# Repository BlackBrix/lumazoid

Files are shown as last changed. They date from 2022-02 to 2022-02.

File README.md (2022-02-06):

# Lumazoid

Firmware for the Lumazoid realtime music visualizer board from nootropic design.
Detailed technical information about Lumazoid is at http://nootropicdesign.com/lumazoid  
  
Shop: https://nootropicdesign.com/store/product-category/led-controllers/  
  
Install libraries/ffft in your Arduino sketchbook libraries folder.

Requires the [Adafruit NeoPixel library](https://github.com/adafruit/Adafruit_NeoPixel). 
Your directory structure should look like this:

```
your_sketchbook
 |
 +--libraries
 |   |
 |   +--ffft
 |   |
 |   +--Adafruit_NeoPixel
 |
 +--Lumazoid
     |
     +--Lumazoid.h
     +--Lumazoid.ino
```

In the Arduino IDE, select board type "Arduino Uno" to upload to the Lumazoid.  
  
https://youtu.be/Vjp7iLEZsX4  
https://youtu.be/2BDE81b42Ac  
https://youtu.be/lYz1uqOQcGg  
https://youtu.be/453p5HPAYZY  
https://youtu.be/N-TBdfP13BE  
  
Forum:  
https://nootropicdesign.com/store/forums/

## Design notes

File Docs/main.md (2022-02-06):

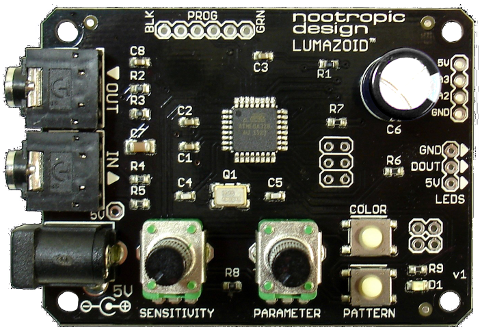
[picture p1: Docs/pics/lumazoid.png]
<div class="et_builder_inner_content et_pb_gutters3"><div class="et_pb_section et_pb_section_0 et_pb_with_background et_section_regular"><div class="et_pb_row et_pb_row_0"><div class="et_pb_column et_pb_column_1_2 et_pb_column_0  et_pb_css_mix_blend_mode_passthrough"><div class="et_pb_module et_pb_image et_pb_image_0 et_pb_image_sticky"><a href="https://nootropicdesign.com/"><span class="et_pb_image_wrap "></span></a></div></div><div class="et_pb_column et_pb_column_1_2 et_pb_column_1  et_pb_css_mix_blend_mode_passthrough et-last-child"><div class="et_pb_button_module_wrapper et_pb_button_0_wrapper et_pb_button_alignment_right et_pb_button_alignment_tablet_left et_pb_button_alignment_phone_left et_pb_module "><a class="et_pb_button et_pb_button_0 et_pb_bg_layout_light" href="/store/product-category/led-controllers/">Buy</a></div></div></div><div class="et_pb_row et_pb_row_1"><div class="et_pb_column et_pb_column_4_4 et_pb_column_2  et_pb_css_mix_blend_mode_passthrough et-last-child"><div class="et_pb_module et_pb_image et_pb_image_1 et_pb_image_sticky"><span class="et_pb_image_wrap "></span></div><div class="et_pb_module et_pb_text et_pb_text_0  et_pb_text_align_left et_pb_bg_layout_light"><div class="et_pb_text_inner"><p>Realtime music visualizer board for LED strips</p></div></div><div class="et_pb_module et_pb_text et_pb_text_1  et_pb_text_align_left et_pb_bg_layout_light"><div class="et_pb_text_inner"><span style="color: #ff5500;">Details</span> | <a href="faq/">FAQ</a> | <a href="/forum/">Forum</a> | <a href="design/">Design Info</a></div></div></div></div><div class="et_pb_row et_pb_row_2"><div class="et_pb_column et_pb_column_1_2 et_pb_column_3  et_pb_css_mix_blend_mode_passthrough"><div class="et_pb_module et_pb_image et_pb_image_2"><span class="et_pb_image_wrap "></span></div></div><div class="et_pb_column et_pb_column_1_2 et_pb_column_4  et_pb_css_mix_blend_mode_passthrough et-last-child"><div class="et_pb_module et_pb_text et_pb_text_2  et_pb_text_align_left et_pb_bg_layout_light"><div class="et_pb_text_inner"><p><span>Lumazoid is a realtime music visualizer board that lets you display an awesome light show that is synchronized to your music. Just plug the Lumazoid in between your music device and your audio system, and enjoy the show!</span></p><ul><li>Works with any WS2812 / WS2812B LED strips like NeoPixel and others</li><li>Supports 60, 120, or 180 LED strip lengths. (video below shows a 2m 120 LED strip)</li><li>8 different patterns + random mode that smoothly transitions between patterns</li><li>3 different color modes with parameter control</li><li>Sensitivity and brightness control</li><li>Adjustable frequency response so you can choose to visualize all frequency bands or just the bass and beat</li><li>Programmable with Arduino</li><li>Fully assembled and tested</li></ul></div></div></div></div><div class="et_pb_row et_pb_row_3"><div class="et_pb_column et_pb_column_4_4 et_pb_column_5  et_pb_css_mix_blend_mode_passthrough et-last-child"><div class="et_pb_module et_pb_video et_pb_video_0"><div class="et_pb_video_box">
  
  youtube-video (https://www.youtube.com/watch?v=2BDE81b42Ac)

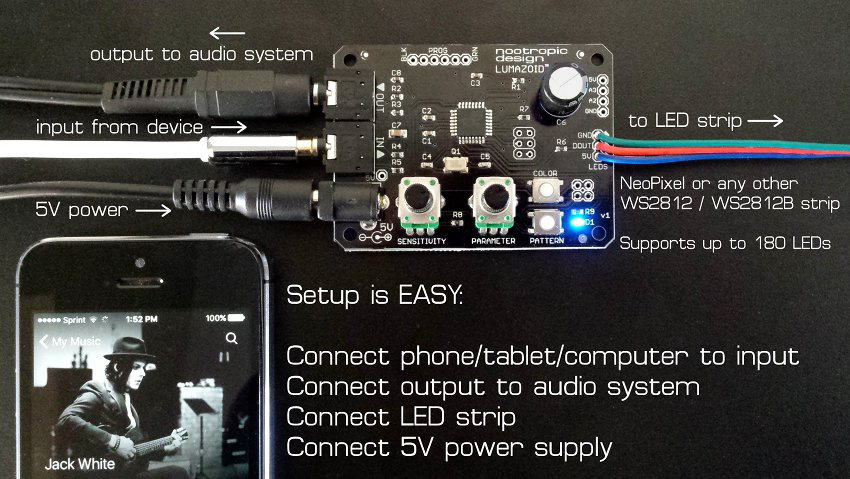
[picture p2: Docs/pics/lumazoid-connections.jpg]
  </div></div></div></div><div class="et_pb_row et_pb_row_4"><div class="et_pb_column et_pb_column_4_4 et_pb_column_6  et_pb_css_mix_blend_mode_passthrough et-last-child"><div class="et_pb_module et_pb_text et_pb_text_3  et_pb_text_align_left et_pb_bg_layout_light"><div class="et_pb_text_inner"><h2>Connection Guide</h2><p><span class="highlight">Input</span>: 3.5mm (1/8″) stereo jack from phone, tablet, computer, Bluetooth receiver or other device.</p><p><span class="highlight">Output</span>: 3.5mm (1/8″) stereo jack to audio system like stereo receiver or amplified computer speakers.</p><p><span class="highlight">LEDs</span>: 3-wire connection to WS2812 / WS2812B LED strip. No wires will be connected if you buy just the board, but if you buy an LED strip from us the Lumazoid board will have a compatible wire harness connected for you.</p><p><span class="highlight">Power</span>: 5V, standard 2.1mm size, center positive</p></div></div></div></div><div class="et_pb_row et_pb_row_5"><div class="et_pb_column et_pb_column_4_4 et_pb_column_7  et_pb_css_mix_blend_mode_passthrough et-last-child"><div class="et_pb_module et_pb_image et_pb_image_3"><span class="et_pb_image_wrap "></span></div></div></div><div class="et_pb_row et_pb_row_6"><div class="et_pb_column et_pb_column_4_4 et_pb_column_8  et_pb_css_mix_blend_mode_passthrough et-last-child"><div class="et_pb_module et_pb_text et_pb_text_4  et_pb_text_align_left et_pb_bg_layout_light"><div class="et_pb_text_inner"><h2>Technical Details</h2><h3>Power</h3><p>The Lumazoid board requires a 5V DC power supply (available in our store). The power supply must be capable of supplying 2A of current when using the Lumazoid with 60 or 120 LEDs (for example, a 1m or 2m strip with 60 LEDs per meter). The Lumazoid firmware is carefully designed to draw less than 2A of current when used with 60 or 120 LEDs. If you use the Lumazoid with a 180 LED strip, you will require a supply that can deliver at least 3A of current, but you probably already have such a power supply if you have that many LEDs. We only sell 2A power supplies at this time.</p><p>If you design and code your own visualizations for Lumazoid, make sure you consider the current requirements of your visualization.</p><h3>LED Strip Compatibility</h3><p>The Lumazoid is designed for WS2812 or WS2812B LED strips. These are readily available from many suppliers (including us) and are sometimes referred to as “NeoPixel” which is Adafruit’s branding for WS2812B strips. Sometimes LED strips are referred to as “WS2811” but the name WS2811 only refers to the driver chip and not the integrated chip+LED combo. If you have an LED strip that someone called “WS2811” and it has 3 wires (5V, ground, and data) then it should work.</p><p><i>The Lumazoid does NOT work</i><span>¨NBSP;</span>with other types of LED strips based on different technology like APA102 and APA104 LEDs (for example, Adafruit “DotStar” strips). Lumazoid only works with 3-wire LED strips based on WS2812 or WS2812B technology.</p><p><span class="highlight">IMPORTANT</span>: When connecting the LED strip to the Lumazoid, carefully pay attention to the labels for the connections (GND, DOUT, 5V). The Lumazoid DOUT connects to the LED strip “DI” or “DIN” connection. Do not assume that the wire colors will match or that the order will match! The top-to-bottom ordering of connections on the Lumazoid board is GND, DOUT, 5V, and this order may be different on your LED strip. If you buy an LED strip from us, the order will match. If you buy a Lumazoid Bundle from us (Lumazoid board, power supply, LED strip) the board will have a wire harness that is compatible with the LED strip and you have nothing to worry about.</p><p><span class="highlight">IMPORTANT</span>: Always connect the LED strip before connecting power. Do not connect the LED strip to a powered board.</p></div></div></div></div><div class="et_pb_row et_pb_row_7"><div class="et_pb_column et_pb_column_4_4 et_pb_column_9  et_pb_css_mix_blend_mode_passthrough et-last-child"><div class="et_pb_module et_pb_text et_pb_text_5  et_pb_text_align_left et_pb_bg_layout_light"><div class="et_pb_text_inner"><h2>Instructions for Use</h2><h3>Initial Setup Configuration</h3><p>Before using your Lumazoid, you may need to configure it for your LED strip length and optionally adjust the brightness. By default, the Lumazoid is configured to use a 120 LED strip (for example, a 2m strip with 60 LEDs per meter) and is set for maximum brightness. If you have a different LED stip length or would like to reduce the brighness, follow these instructions.</p></div></div></div></div><div class="et_pb_row et_pb_row_8"><div class="et_pb_column et_pb_column_4_4 et_pb_column_10  et_pb_css_mix_blend_mode_passthrough et-last-child"><div class="et_pb_module et_pb_video et_pb_video_1"><div class="et_pb_video_box">

youtube-video (https://www.youtube.com/watch?v=453p5HPAYZY)

</div></div></div></div><div class="et_pb_row et_pb_row_9"><div class="et_pb_column et_pb_column_4_4 et_pb_column_11  et_pb_css_mix_blend_mode_passthrough et-last-child"><div class="et_pb_module et_pb_text et_pb_text_6  et_pb_text_align_left et_pb_bg_layout_light"><div class="et_pb_text_inner"><p><span class="highlight">Brightness</span>: hold the color button when connecting power. A rainbow of LEDs will be displayed on the first 8 LEDs. Use the parameter knob to change the brightness. When finished, press the color button again and your configuration will be saved to memory. This will be remembered even if power is disconnected.</p><p><span class="highlight">LED strip length</span>: hold the pattern button when connecting power. One, two, or three red LEDs will be displayed. Used the parameter knob to choose your LED strip configuration based on the number of red LEDs:</p><ol><li>60 LEDs</li><li>120 LEDs</li><li>180 LEDs</li></ol><p>When finished, press the pattern button again and your configuration will be saved to memory. This will be remembered even if power is disconnected.</p><h3>Volume and Sensitivity Adjustment</h3><p>Lumazoid works best when your music device volume is set to a high level. Smaller devices like phones and tablets will need their volume turned up to the highest level. Use the sensitivity knob to adjust the sensitivity of the Lumazoid. Small devices will require a higher sensitivity setting. A music device like a computer may not need a high sensitivity at all. Just experiment with your device to ensure that Lumazoid is responding to the music the way you desire.</p><h3>Patterns, Color Modes, and Frequency Response</h3><p>Lumazoid lets you choose from different LED patterns and color modes. You can also adjust the frequency response.</p></div></div></div></div><div class="et_pb_row et_pb_row_10"><div class="et_pb_column et_pb_column_4_4 et_pb_column_12  et_pb_css_mix_blend_mode_passthrough et-last-child"><div class="et_pb_module et_pb_video et_pb_video_2"><div class="et_pb_video_box">

youtube-video (https://www.youtube.com/watch?v=N-TBdfP13BE)
  
  </div></div></div></div><div class="et_pb_row et_pb_row_11"><div class="et_pb_column et_pb_column_4_4 et_pb_column_13  et_pb_css_mix_blend_mode_passthrough et-last-child"><div class="et_pb_module et_pb_text et_pb_text_7  et_pb_text_align_left et_pb_bg_layout_light"><div class="et_pb_text_inner"><p><b class="highlight">Patterns:<span></span></b>Lumazoid has different display patterns for visualizing the audio signal peaks (high amplitude) detected in music. Lumazoid is like a graphic equalizer that shows the strength of different frequency bands, but Lumazoid displays the information in a much more interesting way. There are 8 different patterns for displaying the audio peaks in the music. Press the pattern button to cycle through them. A white LED indicates which pattern is selected. The 9th pattern is “random” mode which is indicated by a red LED. This mode changes the pattern randomly with a random time interval. The 8 patterns are:</p><ol><li><b>Dance Party</b>: Audio signal peaks are emitted from the center of the strip and fade out as they approach the ends. The speed of the peak is proportional to the audio signal magnitude of that peak.</li><li><b>Dance Party 2</b>: Same as Dance Party but the signal peaks are emitted from one end.</li><li><b>Pulse</b>: Signal peaks are displayed as bright pulses that come from the center of the strip. The width of the pulse is based on signal peak magnitude.</li><li><b>Light Bar</b>: Signal peaks illuminate the entire strip. There is some subtle color variation between LEDs and some motion to make it more interesting.</li><li><b>Color Bars</b>: Signal peaks displayed as colored bars that fade out.</li><li><b>Color Bars 2</b>: Similar to Color Bars but each bar shrinks in size as it fades out.</li><li><b>Flash Bulbs</b>: Signal peaks are displayed as a single-LED flash at a random location. The initial color is white and then fades as a different color.</li><li><b>Fireflies</b>: Signal peaks displayed as single LEDs at a random location and they move left or right as they fade out. Their speed is based on the signal peak magnitude.</li></ol><p><b class="highlight">Color Modes:<span></span></b>Lumazoid has 3 different color modes. Press the color button to cycle through them. The chosen mode is indicated by a blue LED at the beginning of the strip.</p><ol><li><b>Random two-color scheme</b>: Two random colors are chosen and are used to display the signal peaks. Over time, new colors will be chosen. Use the parameter knob to control how fast the color schemes change. If the parameter knob is set to the highest level, the colors will change constantly, therefore giving each signal peak a new color. Setting the parameter to the midpoint is a good position for this color mode.</li><li><b>Rainbow cycling</b>: All signal peaks are displayed as the same color (with a small amount of random variation) and the color shifts through the rainbow over time. Use the parameter knob to control how fast the color shifts through the rainbow.</li><li><b>Frequency color</b>: In this mode, each signal peak is colored depending on the frequency band of that peak. The lowest band is red, with higher frequency bands moving up the spectrum. There are 8 frequency bands: red, orange, yellow, green, cyan, blue, magenta, white. This color mode is most interesting when the frequency response of the Lumazoid is set to respond to all frequency bands (see below). If the frequency response is set to only respond to bass frequencies, then only red/orange/yellow peaks will be displayed in this mode.</li></ol><p><b class="highlight">Frequency Response:<span></span></b>You can control which frequency bands the Lumazoid responds to. To set the frequency response, press and hold both the color and pattern buttons. Use the parameter knob to select how many of the 8 frequency bands will be visualized by the Lumazoid. If you want to only visualize the bass and beat of the music, set the frequency response to only the lower 2 or 3 bands. If you want to visualize all the frequencies in the music (like vocals and higher-pitched instruments), select all the frequency bands.</p><h3></h3><h3></h3><h3>Some Suggested Settings</h3><ul><li>Dance Party or Dancy Party 2 pattern, color mode = 1 (two-color scheme), parameter knob set to midway, frequency response set to lower 3 frequency bands. This creates two-color schemes that change over time.</li><li>Dance Party or Dancy Party 2 pattern, color mode = 3 (frequency colors), frequency response set to include all frequency bands. This setting lets you really visualize the different components of the music. The beat will be red/orange, vocals cyan/blue/magenta, etc.</li><li>Random pattern mode, color mode = 1, parameter knob set to highest level. Each signal peak will be a random color, which looks good on lots of the patterns.</li><li>Random pattern mode, color mode = 2 (rainbow cycling), parameter knob set to mid-high level. All peaks the same base color (with some random variation) and the base color shifts through the rainbow.</li></ul></div></div></div></div><div class="et_pb_row et_pb_row_12"><div class="et_pb_column et_pb_column_4_4 et_pb_column_14  et_pb_css_mix_blend_mode_passthrough et-last-child"><div class="et_pb_module et_pb_text et_pb_text_8  et_pb_text_align_left et_pb_bg_layout_light"><div class="et_pb_text_inner"><h2>Source Code</h2><p>The Lumazoid source code is open source and<span></span><a target="_blank" href="https://github.com/nootropicdesign/lumazoid" rel="noopener noreferrer">available on GitHub</a>.</p></div></div></div></div></div></div>

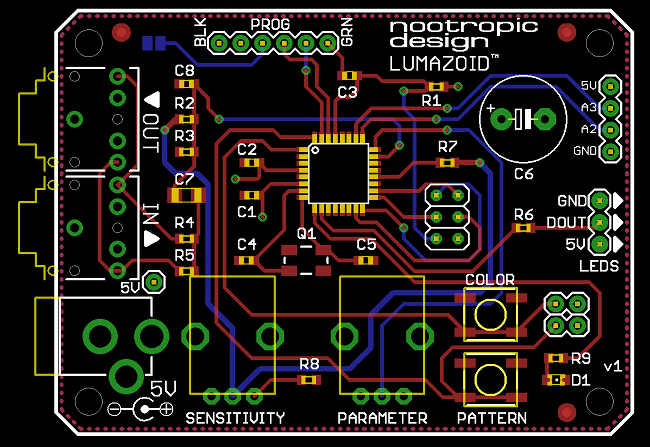
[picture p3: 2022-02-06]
hardware/lumazoid-board_v1.png

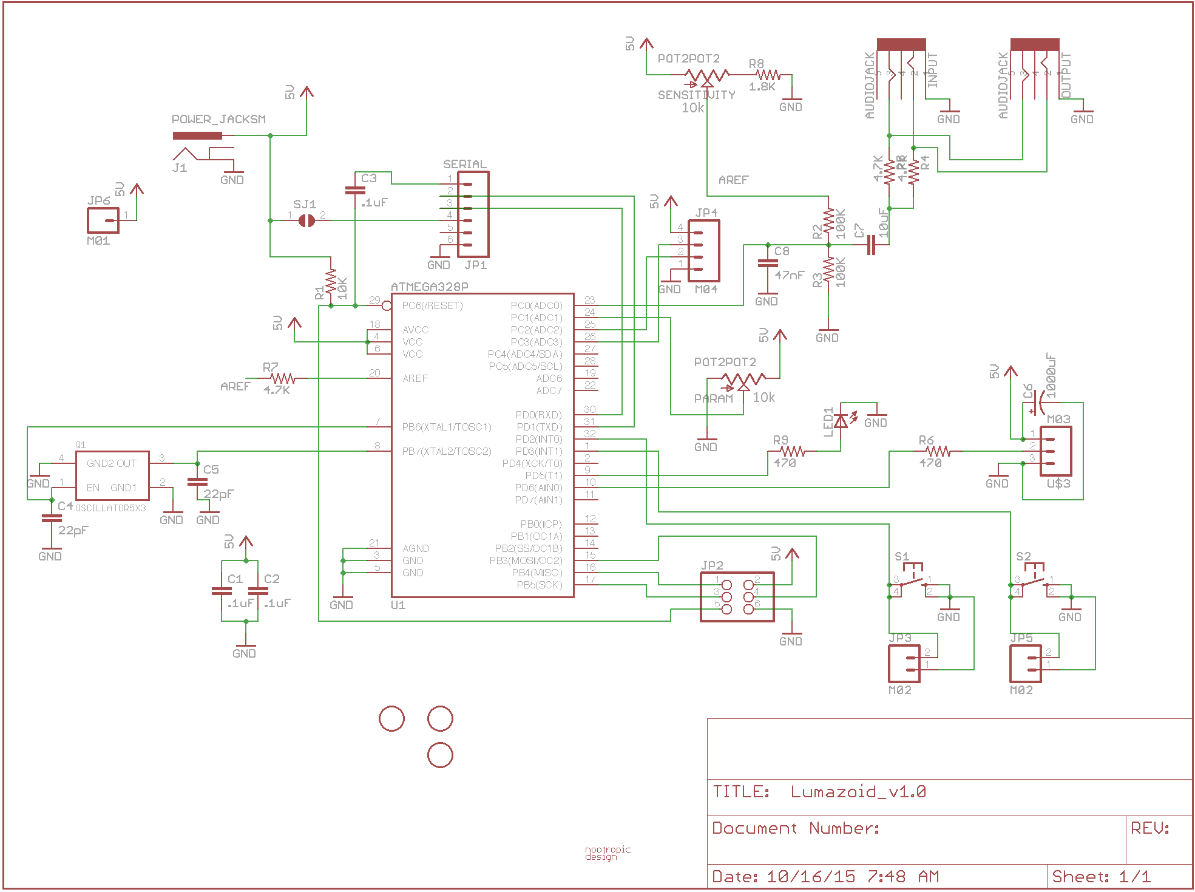
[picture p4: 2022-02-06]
hardware/lumazoid_schematic_v1.0.png

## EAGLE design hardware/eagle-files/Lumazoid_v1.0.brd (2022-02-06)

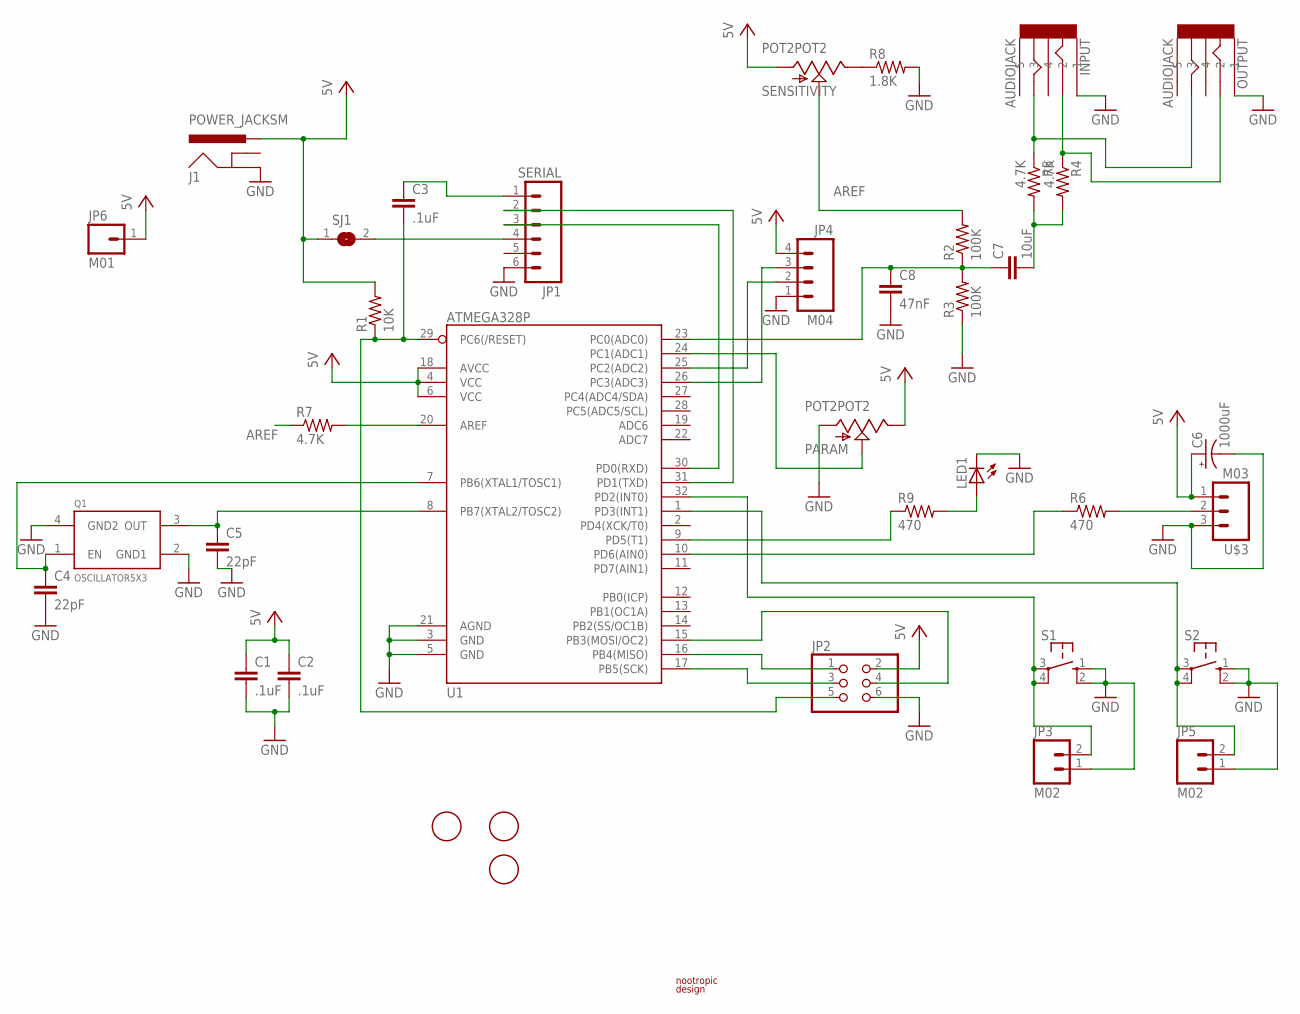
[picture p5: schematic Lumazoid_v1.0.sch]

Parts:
C1, C2, C3: .1uF; C0603
C4, C5: 22pF; C0603
C6: 1000uF; E5-10,5
C7: 10uF; C1206
C8: 47nF; C0603
FID1, FID2, FID3: FIDUCIAL; FIDUCIAL_1MM
INPUT: AUDIOJACK
J1: POWER_JACKSM; POWER_JACK_SM
JP1: SERIAL; 1X06
JP2: PINHD-2X3; 2X03
JP3, JP5: M02; 1X02
JP4: M04; 1X04
JP6: M01; 1X01
LED1: LEDCHIPLED_0805; CHIPLED_0805
OUTPUT: AUDIOJACK
PARAM: POT2POT2; ALPS_POT
Q1: OSCILLATOR5X3; CRYSTAL-SMD-5X3
R1: 10K; R0603
R2, R3: 100K; R0603
R4, R5, R7: 4.7K; R0603
R6, R9: 470; R0603
R8: 1.8K; R0603
S1, S2: SWITCH-TACT6MMSMT-J; DTSM-6-JBEND
SENSITIVITY: POT2POT2; ALPS_POT
SJ1: SJ
U1: ATMEGA328P; TQFP32-08
U$1: LOGO; LOGO_SMALL
U$3: M03; 1X03

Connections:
A0: C7.1, C8.1, R2.1, R3.2, U1.23 (PC0(ADC0))
A1: PARAM.P$2 (2), U1.24 (PC1(ADC1))
A2: JP4.2, U1.25 (PC2(ADC2))
A3: JP4.3, U1.26 (PC3(ADC3))
AREF: R2.2, R7.1, SENSITIVITY.P$2 (2)
D1: JP5.2, S2.3, S2.4 (P1), U1.1 (PD3(INT1))
D2: JP3.2, S1.3, S1.4 (P1), U1.32 (PD2(INT0))
DTR: C3.1, JP1.1
GND: C1.2, C2.2, C4.2, C5.2, C6.-, C8.2, INPUT.1, J1.GND, JP1.6, JP2.6, JP3.1, JP4.1, JP5.1, LED1.C, OUTPUT.1, PARAM.P$1 (1), Q1.2 (GND1), Q1.4 (GND2), R3.1, R8.2, S1.1 (S), S1.2 (S1), S2.1 (S), S2.2 (S1), U1.3 (GND), U1.5 (GND), U1.21 (AGND), U$3.3 (4)
MISO: JP2.1, U1.16 (PB4(MISO))
MOSI: JP2.4, U1.15 (PB3(MOSI/OC2))
unnamed: R6.1, U1.10 (PD6(AIN0))
unnamed: R6.2, U$3.2 (3)
unnamed: INPUT.2, OUTPUT.2, R4.1
unnamed: C5.1, Q1.3 (OUT), U1.8 (PB7(XTAL2/TOSC2))
unnamed: INPUT.3, OUTPUT.3, R5.1
unnamed: C4.1, Q1.1 (EN), U1.7 (PB6(XTAL1/TOSC1))
unnamed: R9.1, U1.9 (PD5(T1))
unnamed: LED1.A, R9.2
unnamed: JP1.4, SJ1.2
unnamed: C7.2, R4.2, R5.2
unnamed: R7.2, U1.20 (AREF)
unnamed: R8.1, SENSITIVITY.P$3 (3)
RESET: C3.2, JP2.5, R1.1, U1.29 (PC6(/RESET))
RX: JP1.3, U1.30 (PD0(RXD))
SCK: JP2.3, U1.17 (PB5(SCK))
TX: JP1.2, U1.31 (PD1(TXD))
VCC: C1.1, C2.1, C6.+, J1.PWR, JP2.2, JP4.4, JP6.1, PARAM.P$3 (3), R1.2, SENSITIVITY.P$1 (1), SJ1.1, U1.4 (VCC), U1.6 (VCC), U1.18 (AVCC), U$3.1 (2)

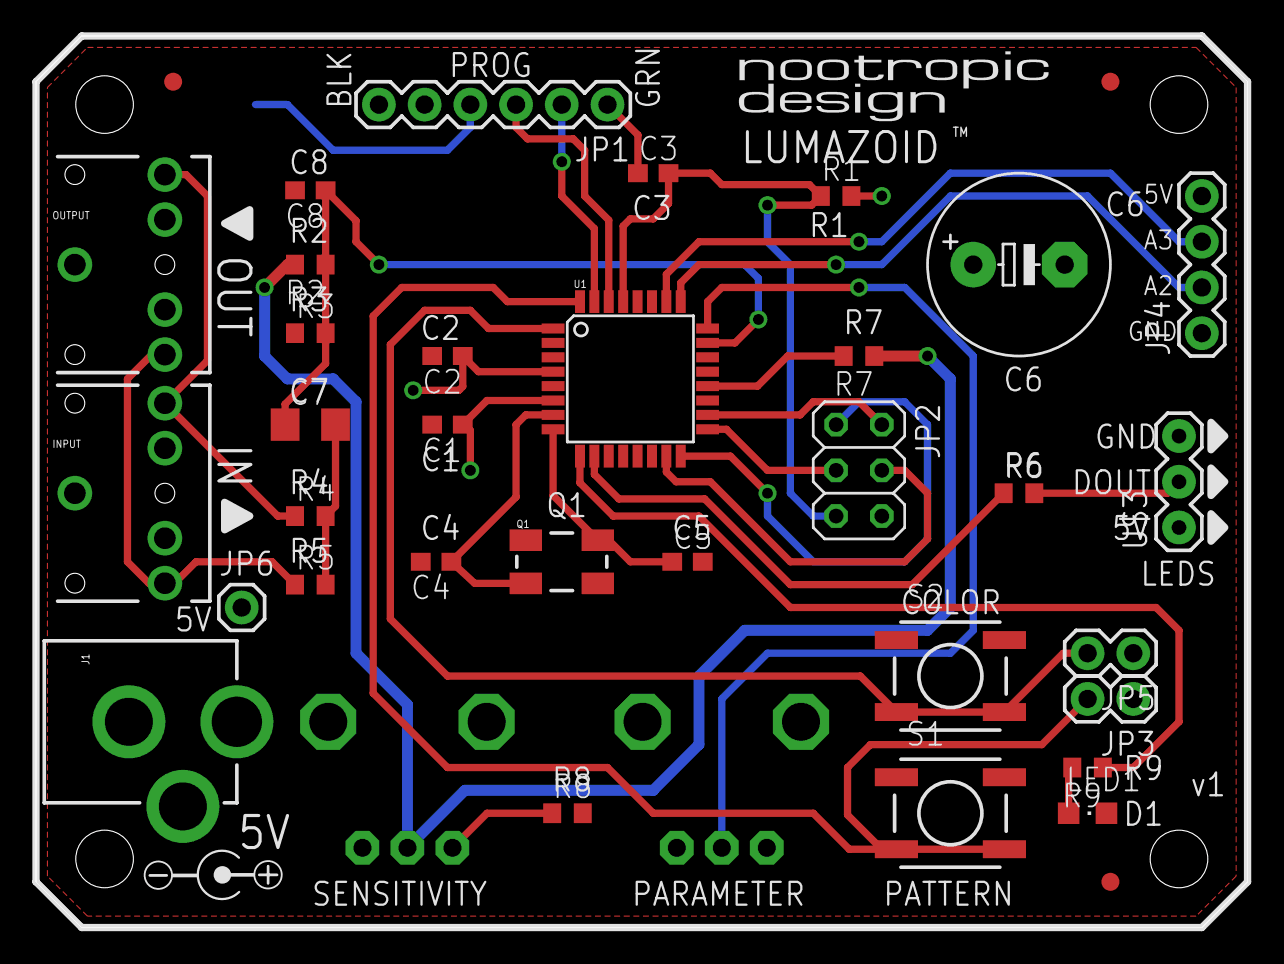
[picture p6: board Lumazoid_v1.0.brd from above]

Board: 2 copper layers, 67.3 x 49.5 mm, 39 parts (1 on the bottom side), 28 nets.

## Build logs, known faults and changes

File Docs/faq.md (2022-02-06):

<div class="et_pb_text_inner"><h2>Frequently Asked Questions</h2><h3>What type of LED strips work with Lumazoid?</h3><p>The Lumazoid is designed for WS2812 or WS2812B LED strips. These are readily available from many suppliers (including us) and are sometimes referred to as “NeoPixel” which is Adafruit’s branding for WS2812B strips. Sometimes LED strips are referred to as “WS2811” but the name WS2811 only refers to the driver chip and not the integrated chip+LED combo. If you have an LED strip that someone called “WS2811” and it has 3 wires (5V, ground, and data) then it should work.</p><p><i>The Lumazoid does NOT work</i><span></span>with other types of LED strips based on different technology like APA102 and APA104 LEDs (for example, Adafruit “DotStar” strips). Lumazoid only works with 3-wire LED strips based on WS2812 or WS2812B technology.</p><h3>What are the power requirements?</h3><p>A 5V power supply capable of supplying 2A of current is required to drive 60 or 120 LEDs (for example, 1m or 2m strips). Even though 120 LEDs can draw more than 2A, the Lumazoid visualizations are carefully designed not to exceed this. We think a 2m 120 LED strip is ideal for Lumazoid because the power supply is more affordable. To drive a 180 LED strip you should use a larger power supply. If you design/code your own visualizations you will need to consider the power requirements of your design.</p><h3>I have a really long LED strip. Can I drive more than 180 LEDs with Lumazoid?</h3><p>Memory constraints prevent Lumazoid from driving visualizations with more than 180 LEDs. But you can drive multiple strips with the<span></span><i>same visualization output</i><span></span>by modifying the code and connecting more strips using the pads A2 and A3 which are broken out on the right side of the board. Make sure you use a power supply capable of delivering enough current to drive all those LEDs.</p><h3>I have a 1 meter 144 LED strip. Can I use the Lumazoid with it?</h3><p>The Lumazoid visualizations are designed to work with multiples of 60 LEDs because these are the most common LED strips. But if you have a 144 LED strip, just contact us and we can provide a Lumazoid configured to work with exactly 144 LEDs. That’s how cool we are.</p><h3>Why isn’t Lumazoid responding much to my music?</h3><p>It’s important to turn the volume of your music device up to a high level, especially if it is a phone or tablet. Also turn up the Lumazoid sensitivity knob to a high level.</p><h3>Can I use a microphone?</h3><p>We’ve had some success with a small electret microphone with amplifier<span></span><a target="_blank" href="https://www.sparkfun.com/products/9964" rel="noopener noreferrer">like this</a><span></span>but it doesn’t work as well as hard-wiring the audio signal. To power an electret microphone, there is a 5V pad right next to the Lumazoid input jack.</p><h3>Instead of connecting the Lumazoid output jack to my audio system, can I use an audio Y-cable from my music device and have one line go to the Lumazoid and one to my audio system?</h3><p>Yes, that generally works, but if the music device does not have a strong audio signal (like a phone), the music can sound muffled (the Lumazoid connection creates a low pass filter in this configuration). When using a computer as the music source, a Y-cable works fine for me.</p><h3>Does Lumazoid work over Bluetooth?</h3><p>No. Our goal was to make the simplest, cheapest way to integrate an LED strip with your music.</p><h3>Can I connect a Lumazoid to an iPod dock?</h3><p>Nope. Our goal was to make the simplest, cheapest way to integrate an LED strip with your music.</p><h3>My Lumazoid doesn’t seem to work. Any ideas?</h3><p>When you apply power does the board’s blue LED come on? It should blink brightly 3 times when power is applied. If this LED is on, then the board is running correctly. Ensure your LED strip is connected properly with the correct connections. Hold down the color button when plugging in power to configure the brightness. If your LED strip is connected properly, you will see the first 8 LEDs on your strip lit up like a rainbow (adjust brightness with parameter knob).</p><h3>How do I program the Lumazoid?</h3><p>Lumazoid is a basically specialized Arduino Uno.<span></span><a target="_blank" href="https://github.com/nootropicdesign/lumazoid" rel="noopener noreferrer">The source code is on GitHub</a>. You can program it via the 6-pin serial connection at the top of the board using a standard FTDI USB to serial cable or adapter. We sell the<span></span><a target="_blank" href="https://nootropicdesign.com/store/product/ftdi-friend/" rel="noopener noreferrer">Adafruit FTDI Friend</a><span></span>which works great and is inexpensive. IMPORTANT: you must connect 5V power when using the FTDI adapter. The 5V VCC line from the adapter is not connected to the Lumazoid to avoid drawing too much current through a USB connection. So, to program using Arduino, connect both the FTDI adapter and normal 5V power to the board. If you are sure you will not draw too much current through the FTDI adapter (for example, you program the board with no LEDs attached), you can solder the jumper on the back of the board which will connect the FTDI 5V line to the board.</p></div>

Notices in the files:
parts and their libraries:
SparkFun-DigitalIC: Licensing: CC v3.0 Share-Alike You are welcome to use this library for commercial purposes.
